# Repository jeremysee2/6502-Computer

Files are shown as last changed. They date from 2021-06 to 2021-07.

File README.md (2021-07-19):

# 6502 Computer based on Ben Eater

While following along Ben Eater's 6502 video series, I attempted to follow along with a breadboard version. However, I found that connecting wires across the breadboard was often confusing and I had to debug a mis-connection more than once. To make things easier on myself, I set out to design my own PCB, following the schematics he had posted on his [website](https://eater.net/6502).

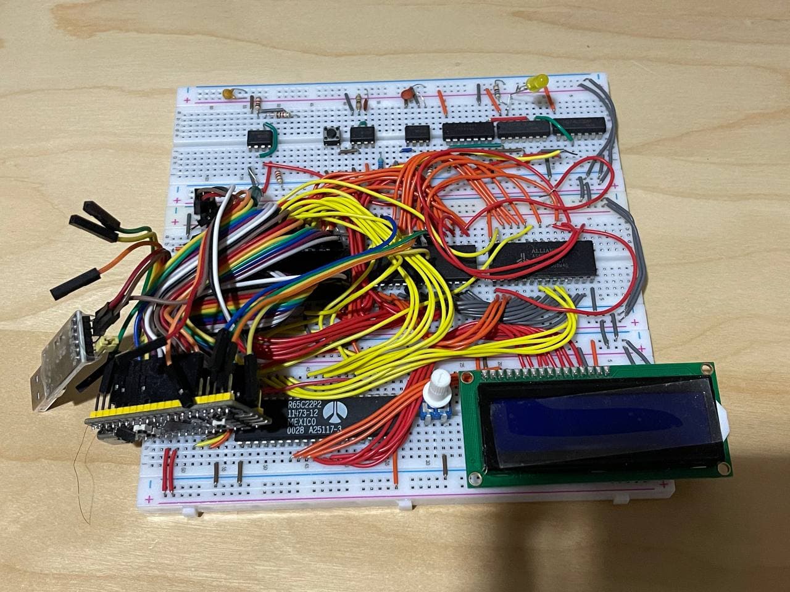
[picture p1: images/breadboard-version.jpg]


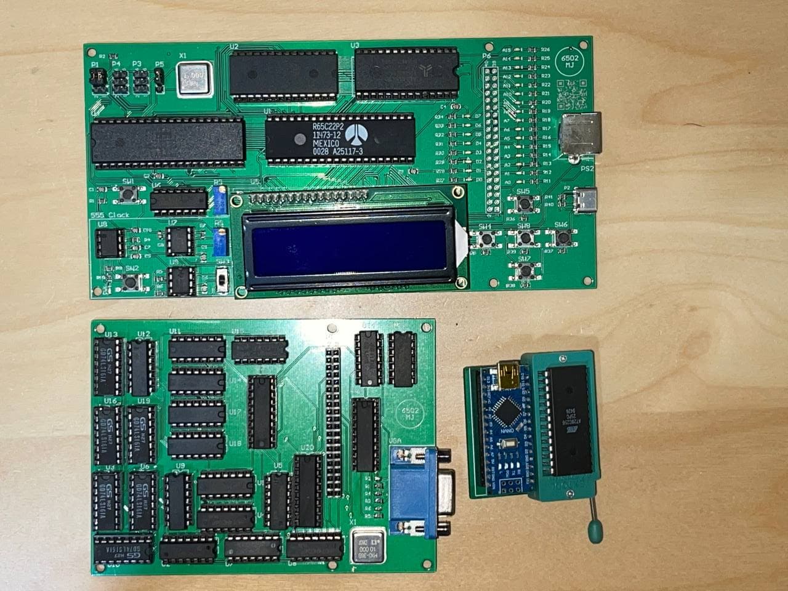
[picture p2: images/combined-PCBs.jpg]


Note that there are two revisions of these boards, as I found some mistakes when fabricating Revision A. In Revision B, I fixed the crystal oscillator footprints (accidentally mirrored them) and 

## 6502 Main PCB

The main PCB follows Ben Eater's 6502 series, comprising the 6502 processor, 62256 SRAM, 28C256 EEPROM, and 65C22 Interface Adapter. Additionally, I incorporated his 555 based clock generator, and PS2 interface. The schematic for this PCB is available [here](PCBs/Rev-B/6502/6502.pdf).

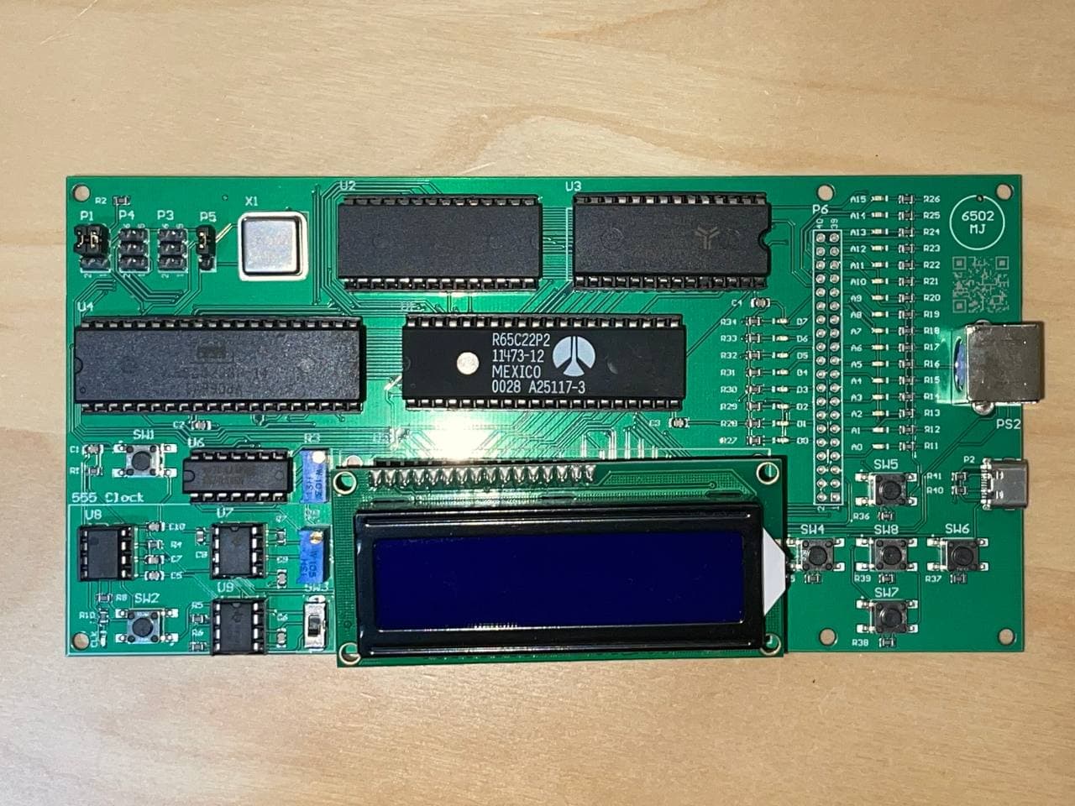
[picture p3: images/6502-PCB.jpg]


## VGA PCB

This follows Ben Eater's [World's Worst Video Card](https://eater.net/vga) series. This comprises a bunch of 74-series logic gates to count VGA clock pulses, which is used to generate appropriate `HSYNC` and `VSYNC` signals for a screen resolution of 200x150 at 10MHz. The schematic for this PCB is available [here](PCBs/Rev-B/6502_VGA/6502_VGA.pdf).

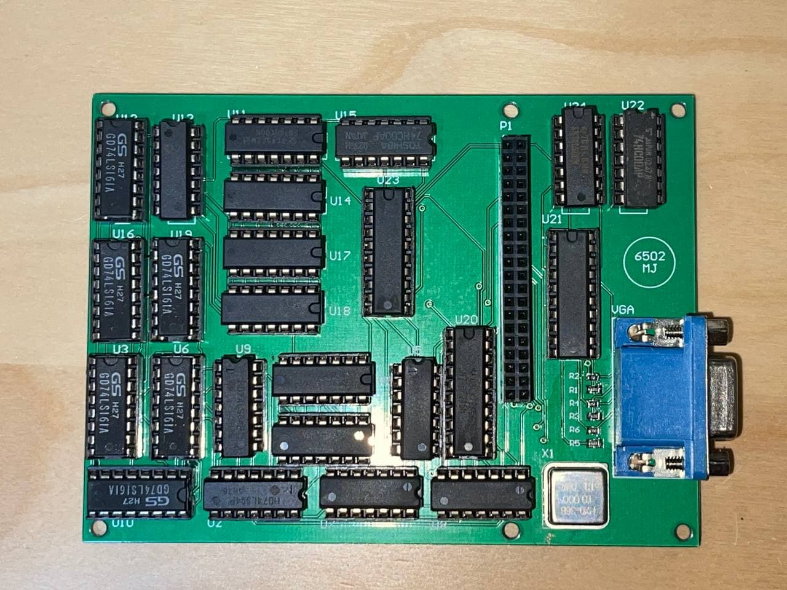
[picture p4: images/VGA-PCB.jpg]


## EEPROM Programmer

This is simply a PCB version of the [EEPROM Programmer](https://github.com/beneater/eeprom-programmer). The schematic for this PCB is available [here](PCBs/Rev-B/EEPROM_Programmer/EEPROM_Programmer.pdf).

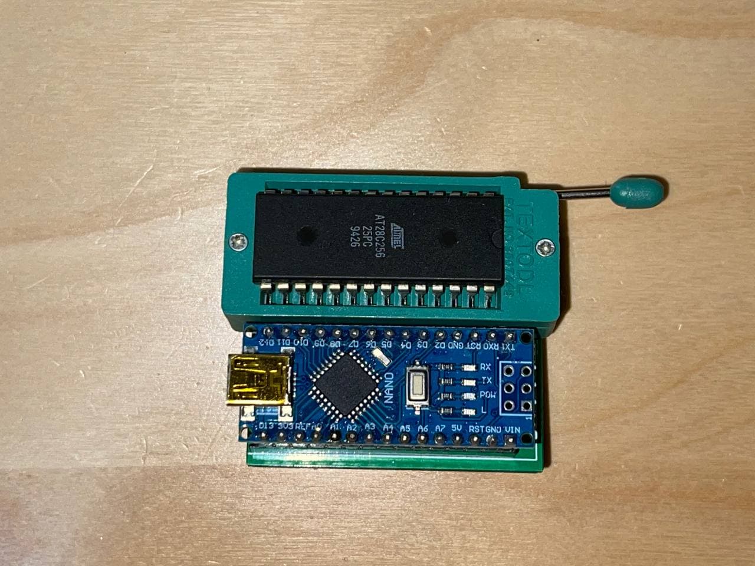
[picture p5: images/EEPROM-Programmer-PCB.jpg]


## Ordering the PCBs

Zip the contents of the "fabrication" folders, that will be the Gerber files you send to your PCB manufacturer. I recommend getting the SMT components (passives, LEDs, USB-C connectors) assembled for you as it can be a pain to solder them without a hot air gun. Get the files for the [6502 Carrier Board](PCBs/Rev-B/6502/fabrication), [VGA Board](vga/../PCBs/Rev-B/6502/fabrication) and [EEPROM Programmer Board](eeprom_programmer/../PCBs/Rev-B/EEPROM_Programmer/fabrication).

For the components, I recommend you buy them from Ben Eater's store for the [6502](https://eater.net/6502), [Clock module](https://eater.net/shop), the [VGA Board](https://eater.net/vga), [EEPROM Programmer (TL866)](https://eater.net/shop). The components for the PS2 circuit are not yet available from his store; you'll need to buy the 74-series logic chips yourself. If you want to buy the components yourself, I still recommend at least getting the 6502 kit and the EEPROM programmer from his store, as I've found that it can be hard to buy genuine "W65C02" chips.

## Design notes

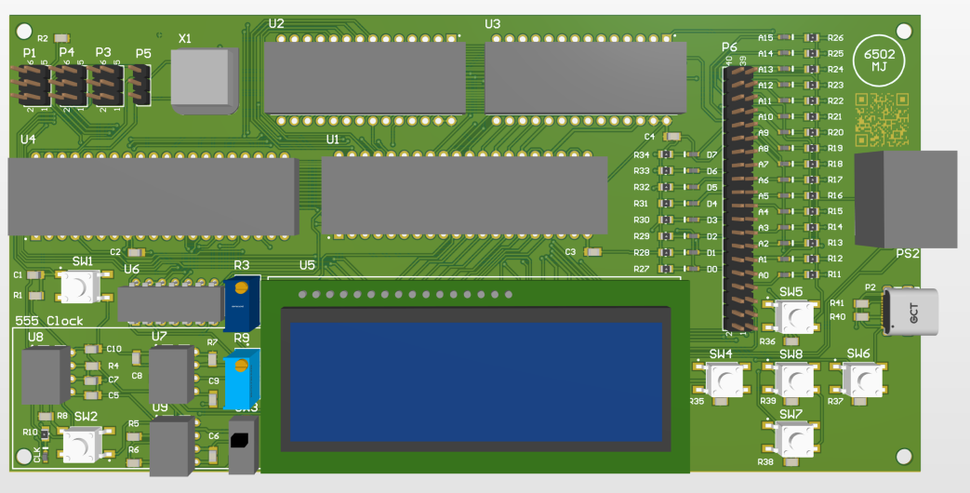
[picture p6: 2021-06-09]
PCBs/Rev-B/6502/3dModel_6502.PNG

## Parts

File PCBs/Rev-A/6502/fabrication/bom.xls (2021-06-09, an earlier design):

Comment | Designator | Package | LCSC Part
19-217/GHC-YR1S2/3T | D0,D1,D2,D3,D4,D5,D6,D7 | EVRL-0603-2_V | C72043
GRM21BR71H104KA01L | C1,C2,C3,C4,C7,C10,C11,C12 | CAPC2013X135X45ML10T25 | C49678
GRM216R61E105KA12D | C8 | CAPC2013X70X45NL10T25 | C28323
19-217/BHC-ZL1M2RY/3T | A0,A1,A2,A3,A4,A5,A6,A7,A8,A9,A10,A11,A12,A13,A14,A15,CLK | EVRL-0603-2_V | C72041
0805W8F5101T5E | R40,R41 | RESC2013X50X30NL20T20 | C27834
CRCW0805220RFKEA | R10,R11,R12,R13,R14,R15,R16,R17,R18,R19,R20,R21,R22,R23,R24,R25,R26,R27,R28,R29,R30,R31,R32,R33,R34 | FP-CRCW0805-E3-MFG | C17557
Diode, General Purpose | D8 | DO-214AC/SMA | C412437
CRCW08051M00JNEA | R4 | RESC2013X50X30NL20T20 | C17514
GRM216R71H103KA01D | C5,C6,C9 | CAPC2013X70X45ML10T25 | C1710
K2-1102SP-C4SC-04 | SW1,SW2,SW4,SW5,SW6,SW7,SW8 | TECO-FSM4JSMA_V | C127509
CRCW08051K00FKEA | R1,R2,R5,R6,R7,R8,R35,R36,R37,R38,R39 | RESC2013X50X30NL20T20 | C17513
0805W8F3302T5E | R42 | RESC2013X50X30NL20T20 | C17633

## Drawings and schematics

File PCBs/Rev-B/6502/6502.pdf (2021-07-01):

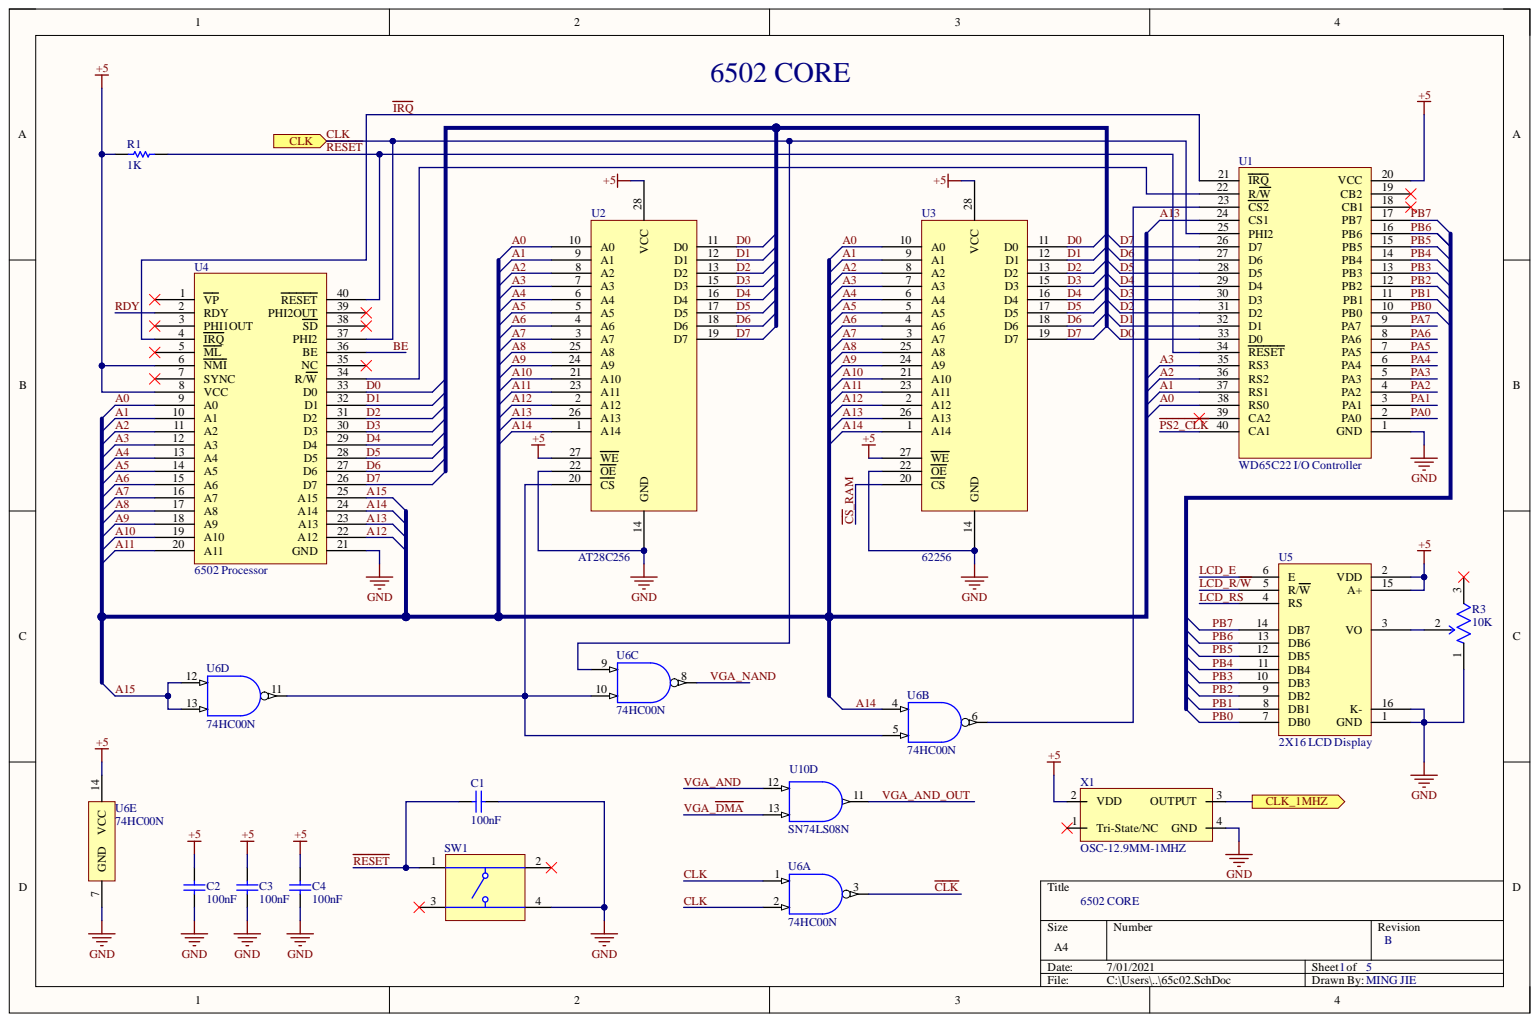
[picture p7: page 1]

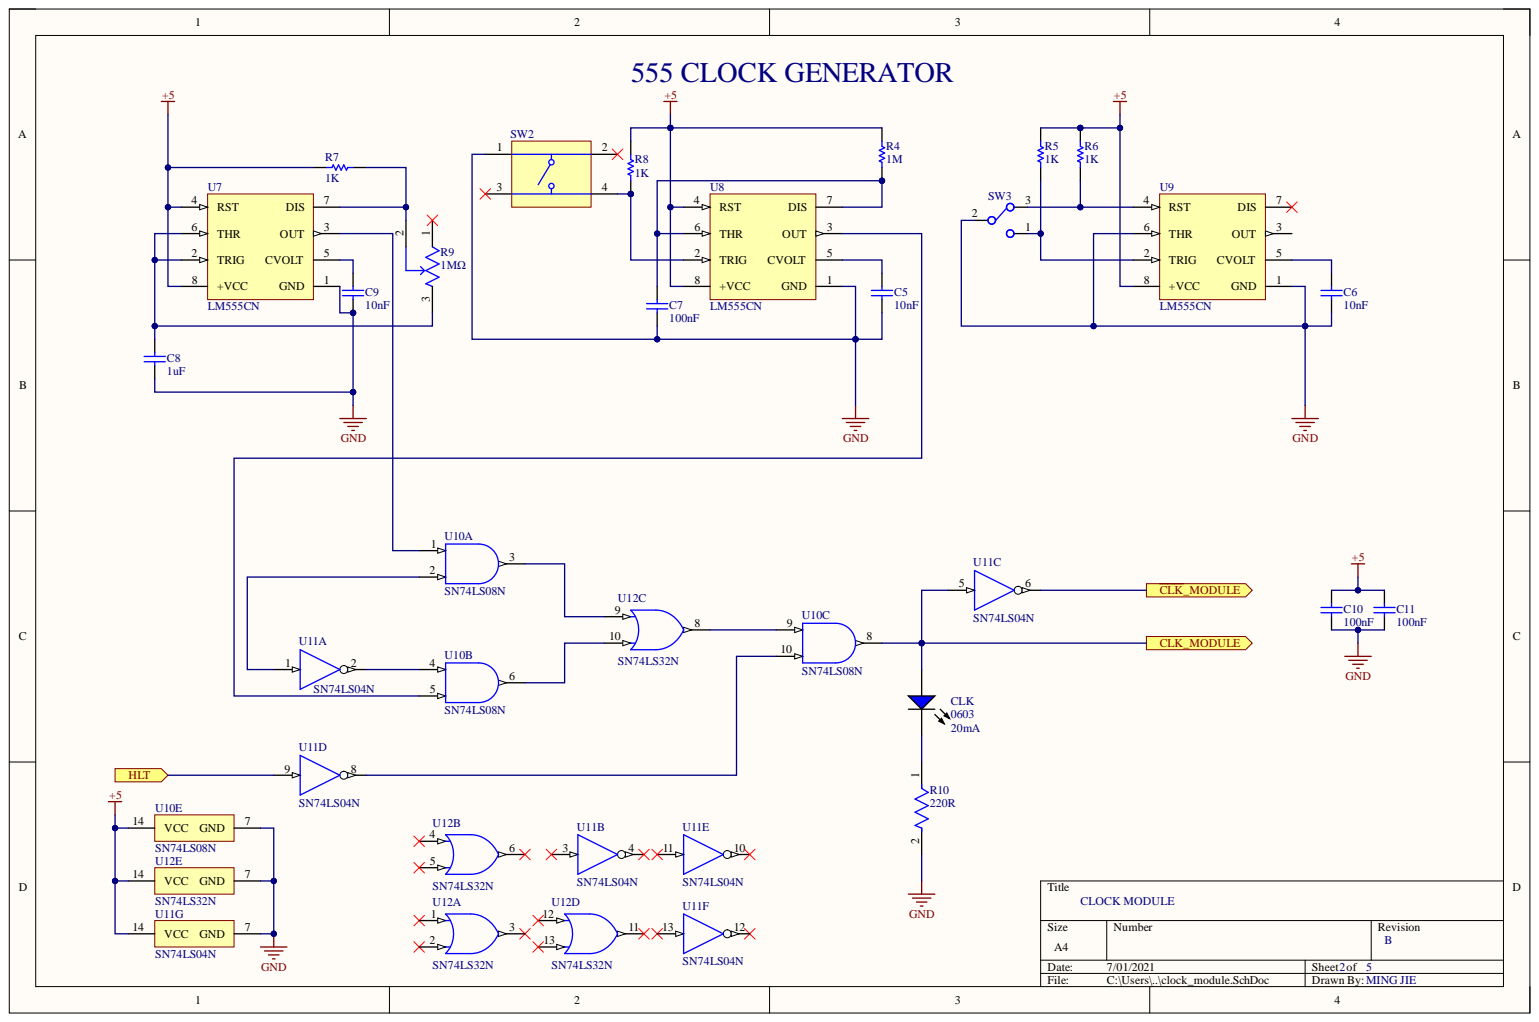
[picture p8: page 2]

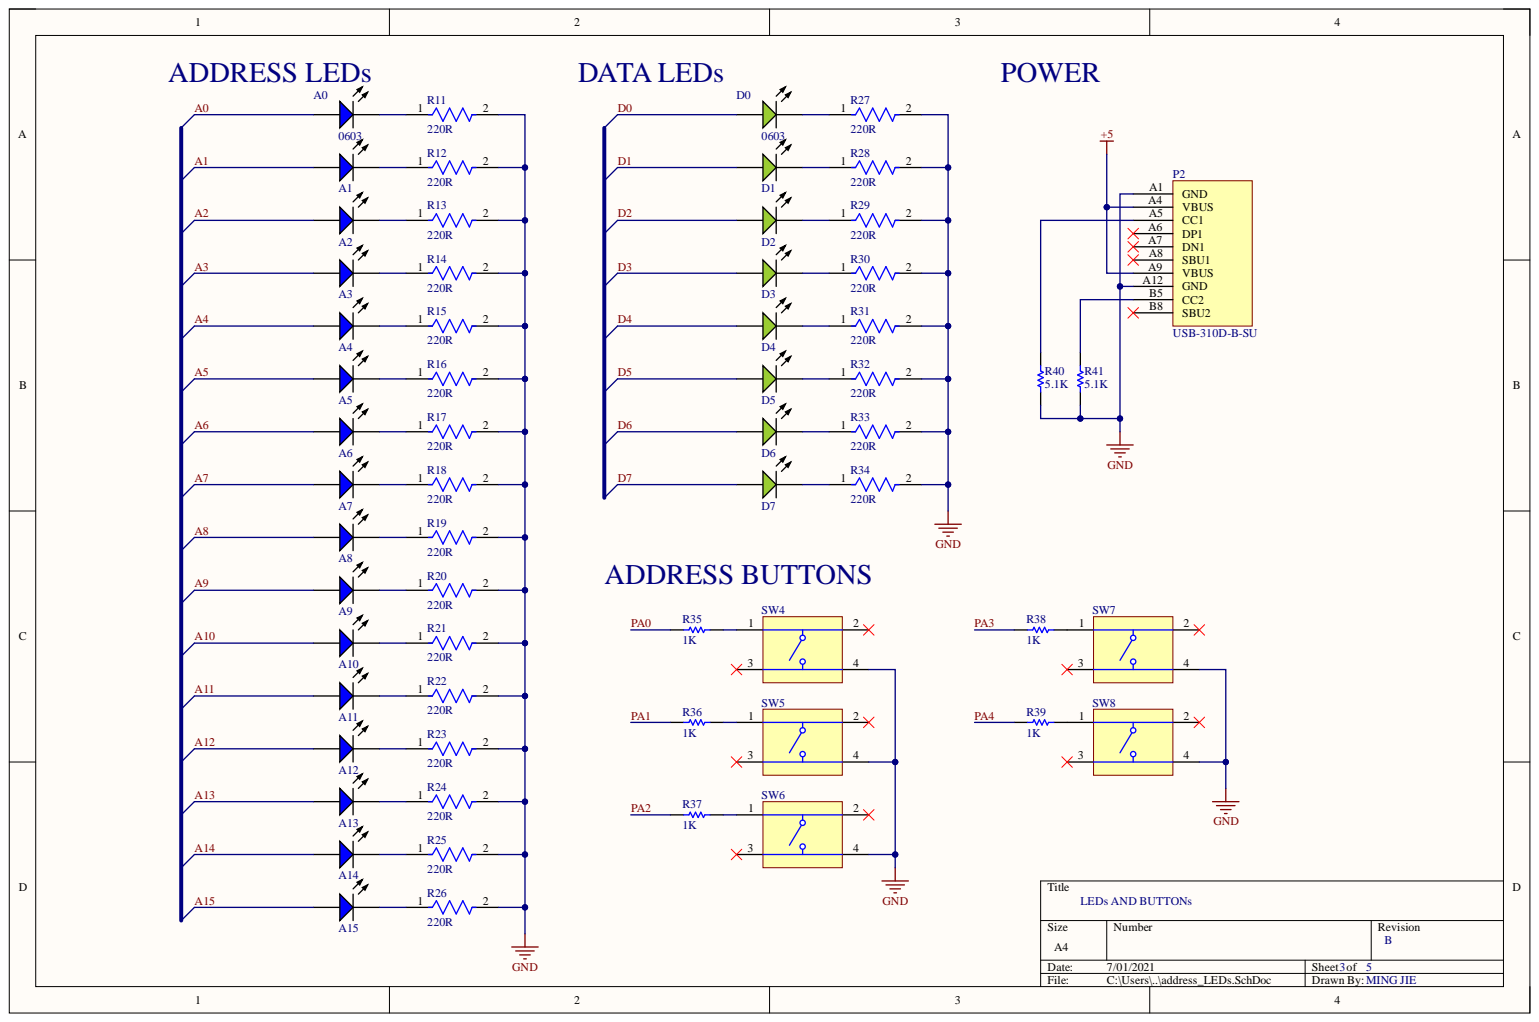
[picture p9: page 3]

A 4
A 5
A 6

A 1 2
CC2 B5

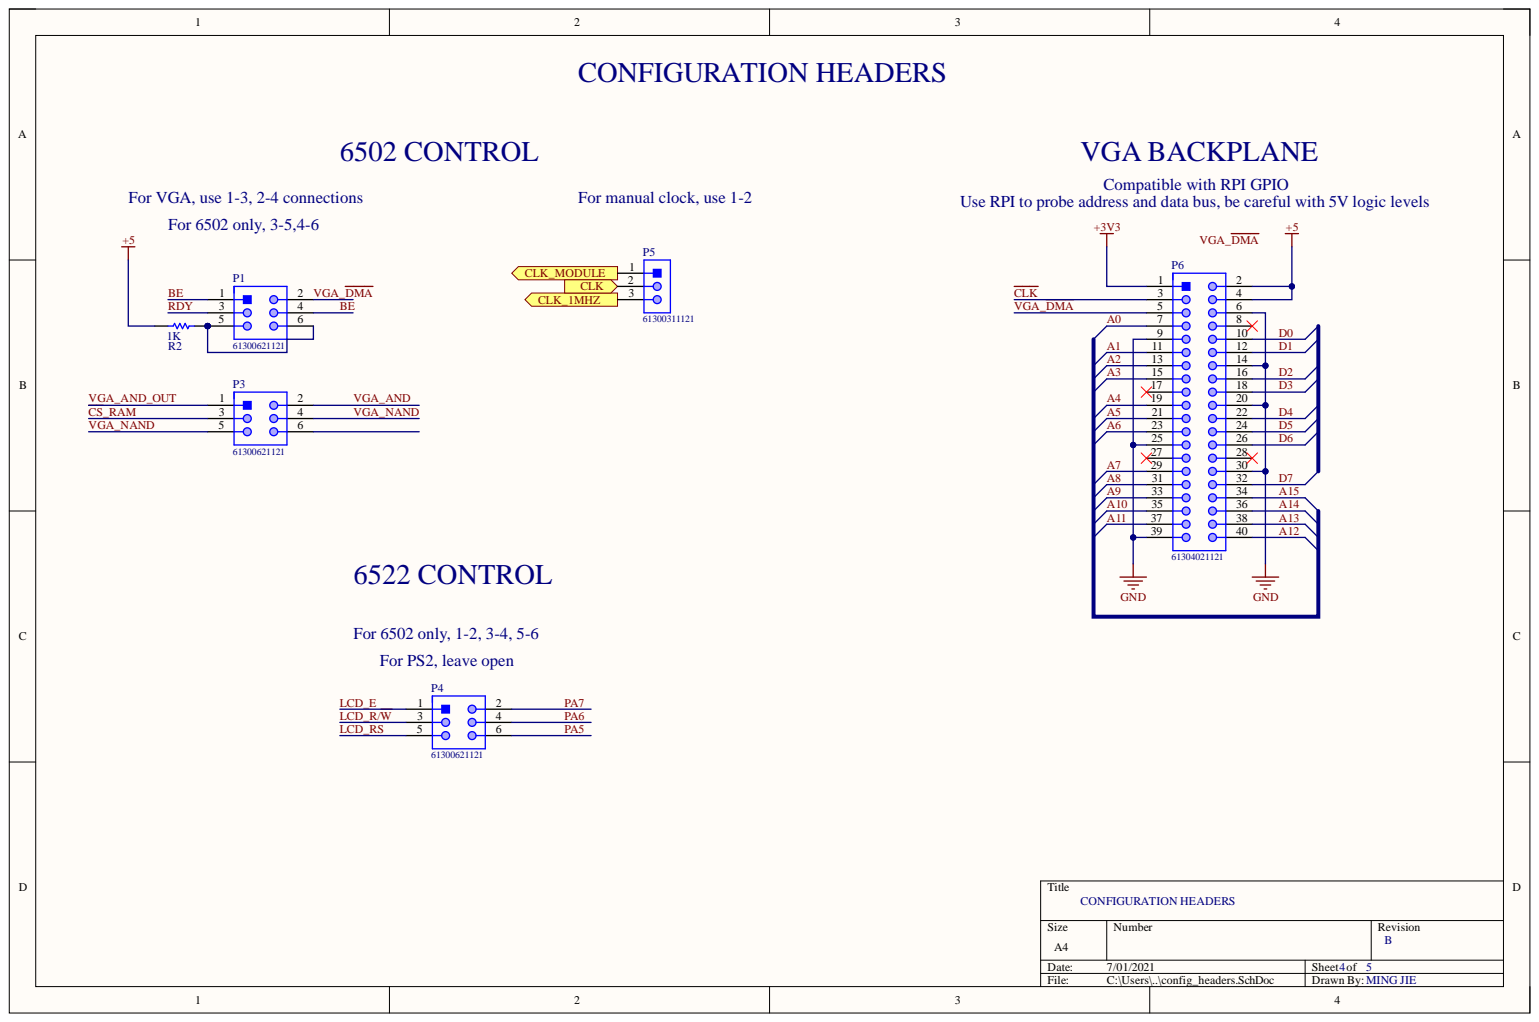
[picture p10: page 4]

to probe address and data bus, be careful

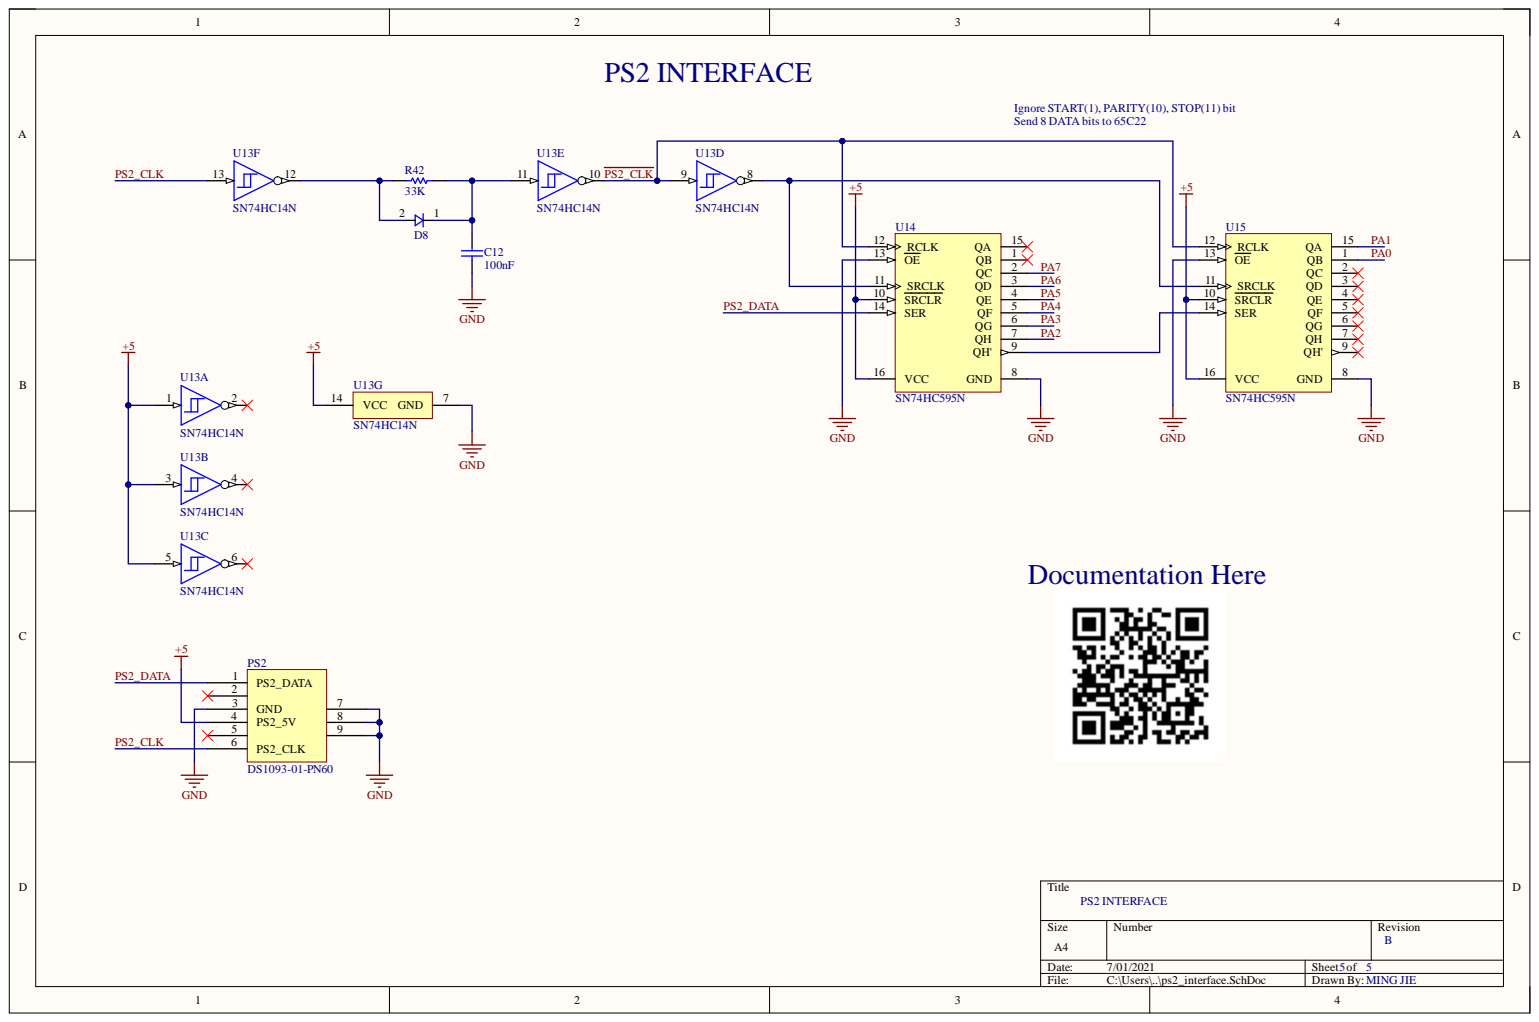
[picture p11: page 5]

Ignore START(1), PARITY(10), STOP(11) bit
Send 8 DATA bits to 65C22

PS2_5V 4 | 8

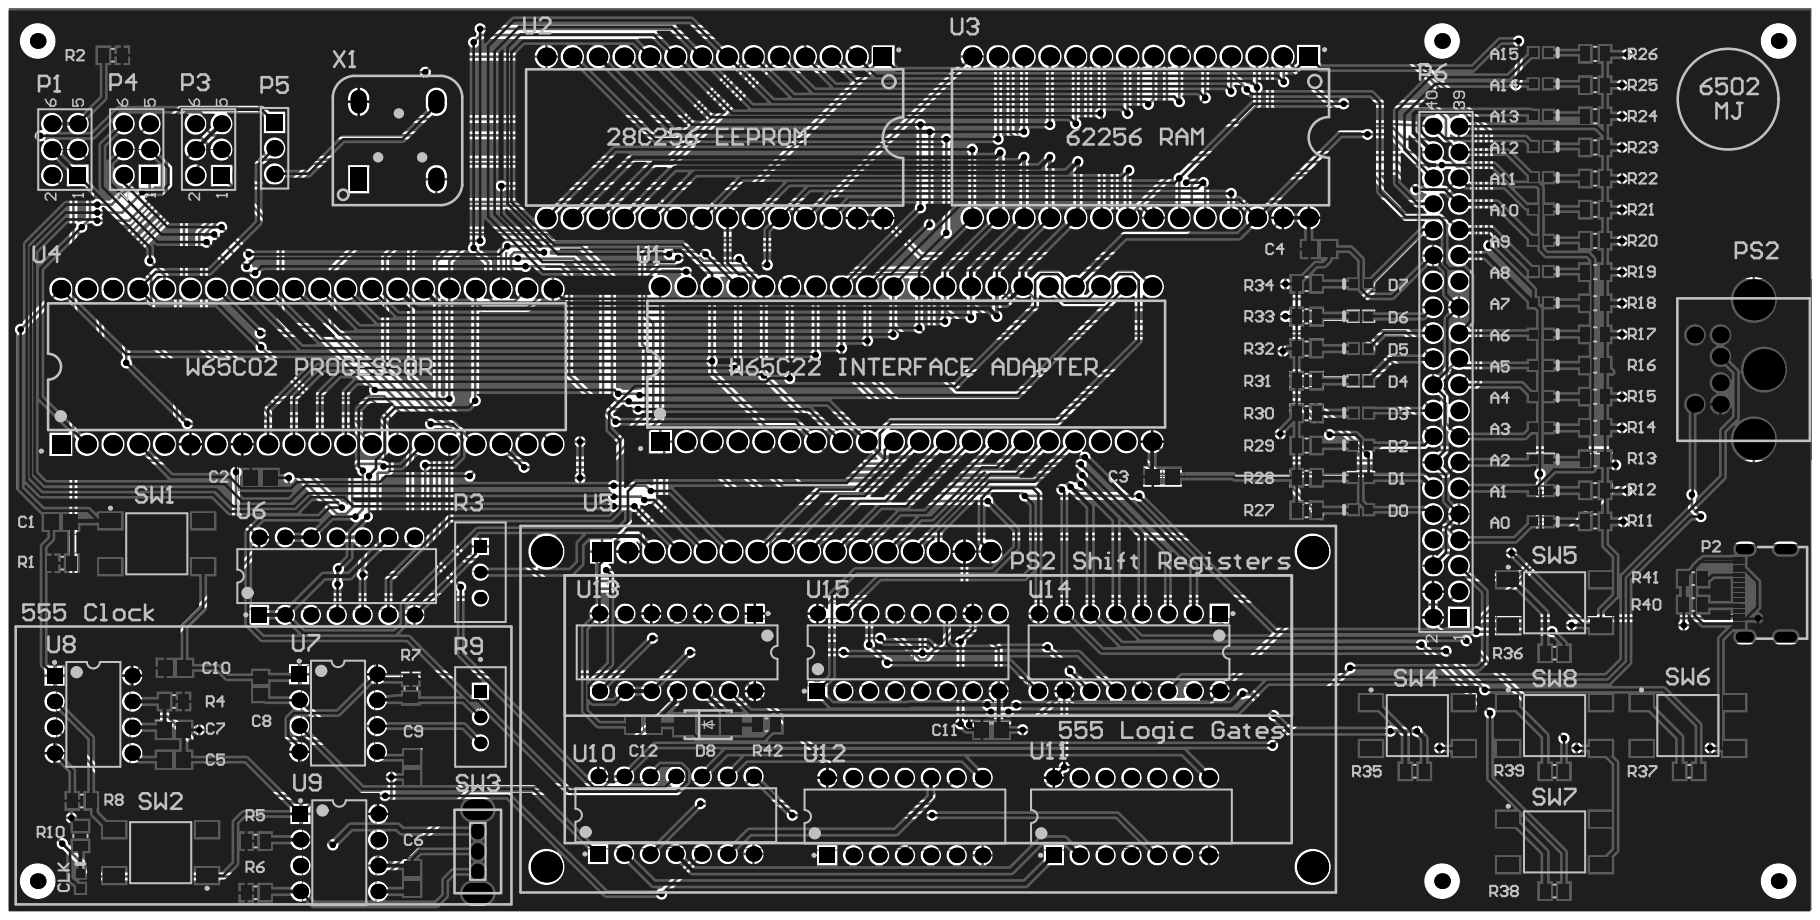
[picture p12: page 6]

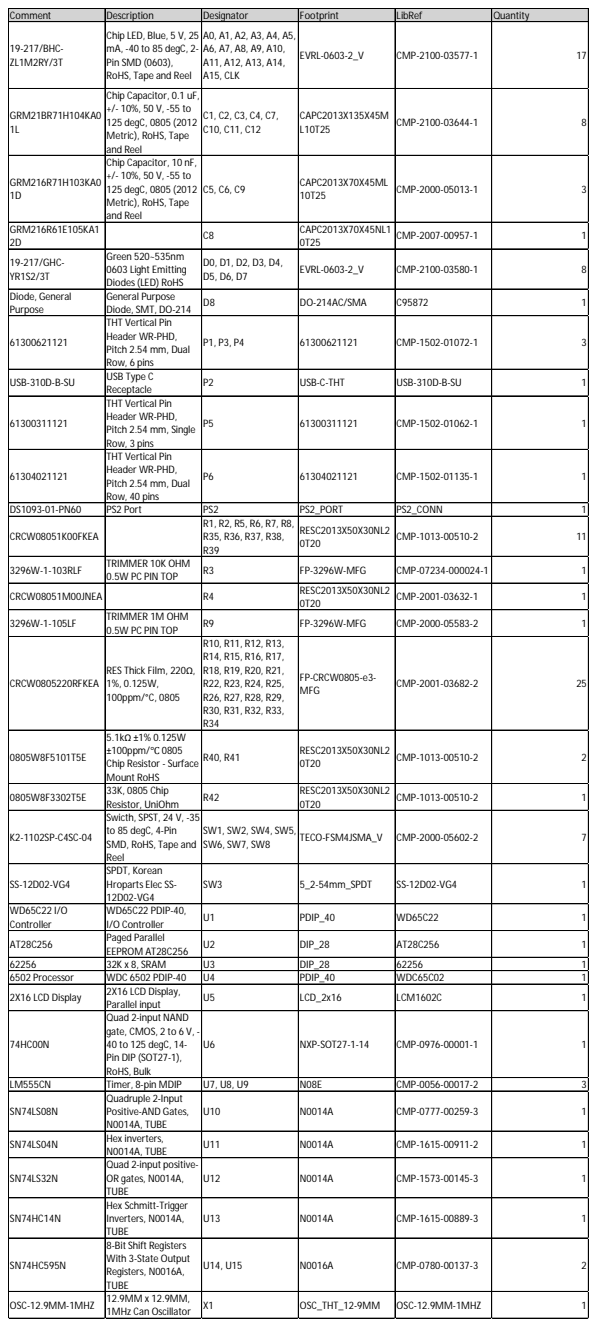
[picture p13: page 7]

Comment | Description | Designator | Footprint | LibRef | Quantity
19-217/BHC-ZL1M2RY/3T | Chip LED, Blue, 5 V, 25 mA, -40 to 85 degC, 2-Pin SMD (0603), RoHS, Tape and Reel | A0, A1, A2, A3, A4, A5, A6, A7, A8, A9, A10, A11, A12, A13, A14, A15, CLK | EVRL-0603-2_V | CMP-2100-03577-1 | 17

GRM21BR71H104KA0 1L | Chip Capacitor, 0.1 uF, +/- 10%, 50 V, -55 to 125 degC, 0805 (2012 Metric), RoHS, Tape and Reel | C1, C2, C3, C4, C7, C10, C11, C12 | CAPC2013X135X45M L10T25 | CMP-2100-03644-1 | 8

GRM216R71H103KA0 1D | Chip Capacitor, 10 nF, +/- 10%, 50 V, -55 to 125 degC, 0805 (2012 Metric), RoHS, Tape and Reel | C5, C6, C9 | CAPC2013X70X45ML 10T25 | CMP-2000-05013-1 | 3

GRM216R61E105KA1 2D | | C8 | CAPC2013X70X45NL1 0T25 | CMP-2007-00957-1 | 1

19-217/GHC-YR1S2/3T | Green 520~535nm 0603 Light Emitting Diodes (LED) RoHS | D0, D1, D2, D3, D4, D5, D6, D7 | EVRL-0603-2_V | CMP-2100-03580-1 | 8

Diode, General Purpose | General Purpose Diode, SMT, DO-214 | D8 | DO-214AC/SMA | C95872 | 1

61300621121 | THT Vertical Pin Header WR-PHD, Pitch 2.54 mm, Dual Row, 6 pins | P1, P3, P4 | 61300621121 | CMP-1502-01072-1 | 3

USB-310D-B-SU | USB Type C Receptacle | P2 | USB-C-THT | USB-310D-B-SU | 1

61300311121 | THT Vertical Pin Header WR-PHD, Pitch 2.54 mm, Single Row, 3 pins | P5 | 61300311121 | CMP-1502-01062-1 | 1

61304021121 | THT Vertical Pin Header WR-PHD, Pitch 2.54 mm, Dual Row, 40 pins | P6 | 61304021121 | CMP-1502-01135-1 | 1

DS1093-01-PN60 | PS2 Port | PS2 | PS2_PORT | PS2_CONN | 1
CRCW08051K00FKEA | | R1, R2, R5, R6, R7, R8, R35, R36, R37, R38, R39 | RESC2013X50X30NL2 0T20 | CMP-1013-00510-2 | 11

3296W-1-103RLF | TRIMMER 10K OHM 0.5W PC PIN TOP | R3 | FP-3296W-MFG | CMP-07234-000024-1 | 1

CRCW08051M00JNEA | | R4 | RESC2013X50X30NL2 0T20 | CMP-2001-03632-1 | 1

3296W-1-105LF | TRIMMER 1M OHM 0.5W PC PIN TOP | R9 | FP-3296W-MFG | CMP-2000-05583-2 | 1

CRCW0805220RFKEA | RES Thick Film, 220Ω, 1%, 0.125W, 100ppm/°C, 0805 | R10, R11, R12, R13, R14, R15, R16, R17, R18, R19, R20, R21, R22, R23, R24, R25, R26, R27, R28, R29, R30, R31, R32, R33, R34 | FP-CRCW0805-e3-MFG | CMP-2001-03682-2 | 25

0805W8F5101T5E | 5.1kΩ ±1% 0.125W ±100ppm/℃ 0805 Chip Resistor - Surface Mount RoHS | R40, R41 | RESC2013X50X30NL2 0T20 | CMP-1013-00510-2 | 2

0805W8F3302T5E | 33K, 0805 Chip Resistor, UniOhm | R42 | RESC2013X50X30NL2 0T20 | CMP-1013-00510-2 | 1

K2-1102SP-C4SC-04 | Swicth, SPST, 24 V, -35 to 85 degC, 4-Pin SMD, RoHS, Tape and Reel | SW1, SW2, SW4, SW5, SW6, SW7, SW8 | TECO-FSM4JSMA_V | CMP-2000-05602-2 | 7

SS-12D02-VG4 | SPDT, Korean Hroparts Elec SS-12D02-VG4 | SW3 | 5_2-54mm_SPDT | SS-12D02-VG4 | 1

WD65C22 I/O Controller | WD65C22 PDIP-40, I/O Controller | U1 | PDIP_40 | WD65C22 | 1

AT28C256 | Paged Parallel EEPROM AT28C256 | U2 | DIP_28 | AT28C256 | 1

62256 | 32K x 8, SRAM | U3 | DIP_28 | 62256 | 1
6502 Processor | WDC 6502 PDIP-40 | U4 | PDIP_40 | WDC65C02 | 1
2X16 LCD Display | 2X16 LCD Display, Parallel input | U5 | LCD_2x16 | LCM1602C | 1

74HC00N | Quad 2-input NAND gate, CMOS, 2 to 6 V, -40 to 125 degC, 14-Pin DIP (SOT27-1), RoHS, Bulk | U6 | NXP-SOT27-1-14 | CMP-0976-00001-1 | 1

LM555CN | Timer, 8-pin MDIP | U7, U8, U9 | N08E | CMP-0056-00017-2 | 3
SN74LS08N | Quadruple 2-Input Positive-AND Gates, N0014A, TUBE | U10 | N0014A | CMP-0777-00259-3 | 1

SN74LS04N | Hex inverters, N0014A, TUBE | U11 | N0014A | CMP-1615-00911-2 | 1

SN74LS32N | Quad 2-input positive-OR gates, N0014A, TUBE | U12 | N0014A | CMP-1573-00145-3 | 1

SN74HC14N | Hex Schmitt-Trigger Inverters, N0014A, TUBE | U13 | N0014A | CMP-1615-00889-3 | 1

SN74HC595N | 8-Bit Shift Registers With 3-State Output Registers, N0016A, TUBE | U14, U15 | N0016A | CMP-0780-00137-3 | 2

OSC-12.9MM-1MHZ | 12.9MM x 12.9MM, 1MHz Can Oscillator | X1 | OSC_THT_12-9MM | OSC-12.9MM-1MHZ | 1

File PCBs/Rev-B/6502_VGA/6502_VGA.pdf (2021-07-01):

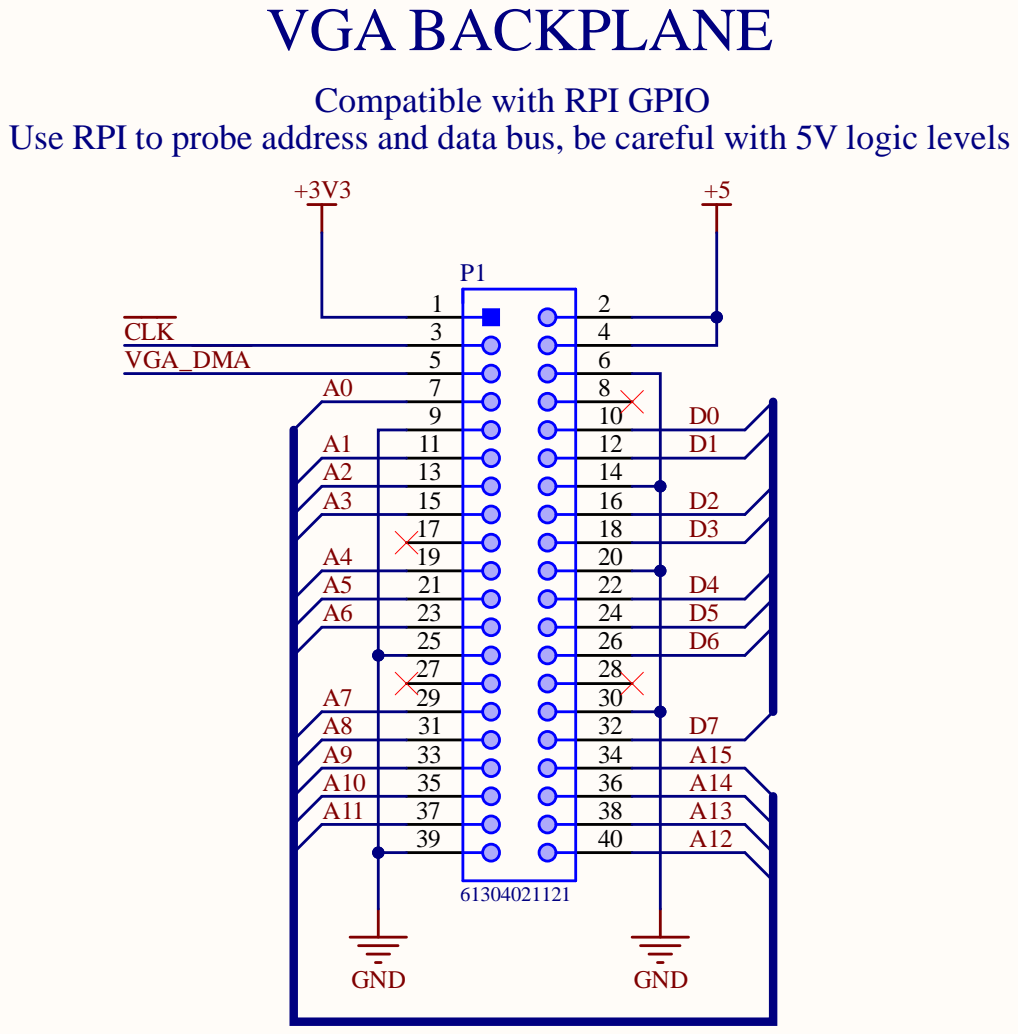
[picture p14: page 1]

to probe address and data bus, be careful

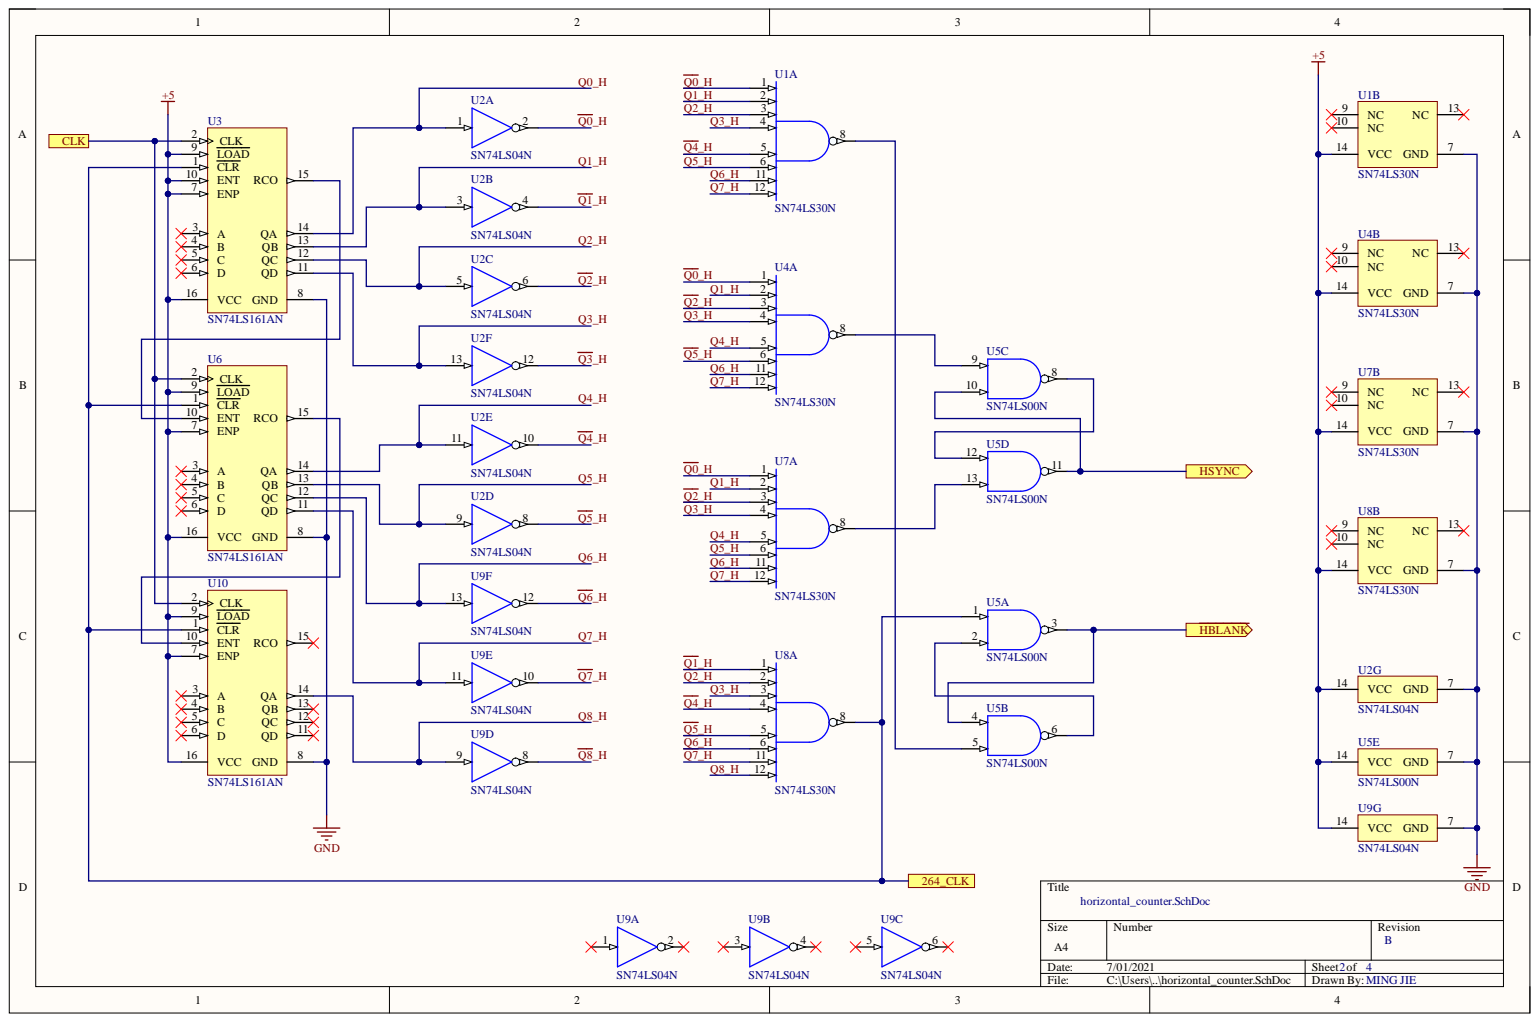
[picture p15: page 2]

4 | | 1 3
5 | | 1 2 | | 2
6 | | 1 1

4 | 1 3
5 | 1 2 | U 2 D | 5
6 | 1 1

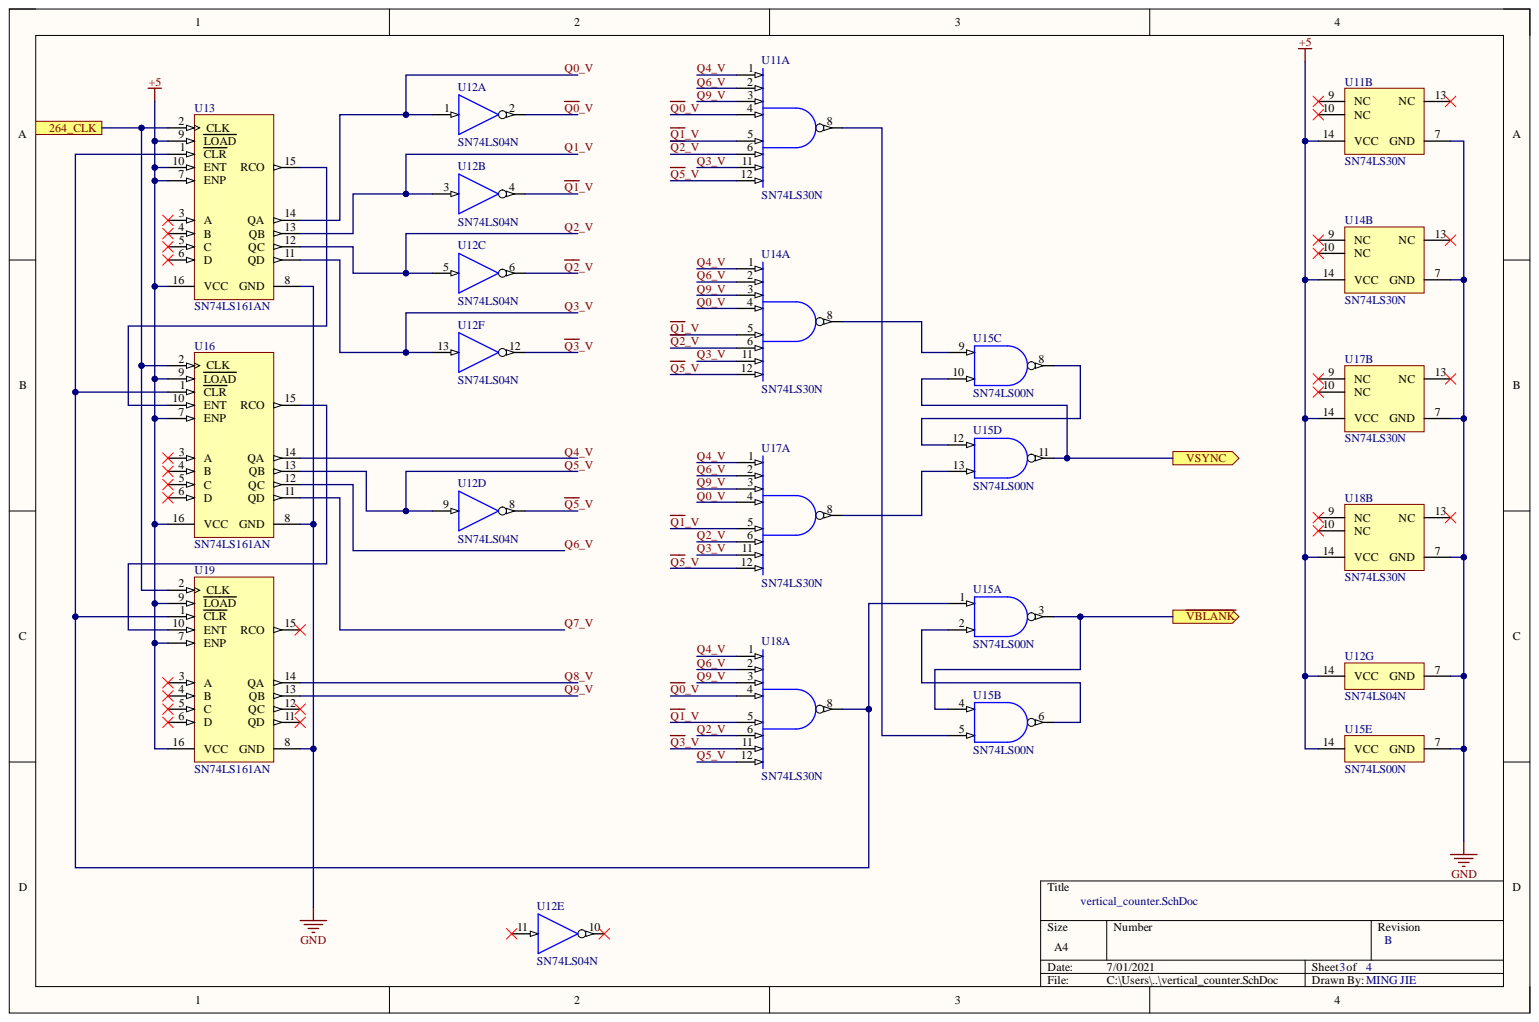
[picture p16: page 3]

4 | 1 3
5 | 1 2
6 | 1 1

1 0
7 | 1 4

4 | 1 3 | Q 5
1 6 | 8 | | 9 | 8 | Q

1 0 | E N T RCO E N P A Q A B Q B C Q C D Q D VCC G N D | 1 5 | SN 7 4 LS3 0 N
7 | | 1 4

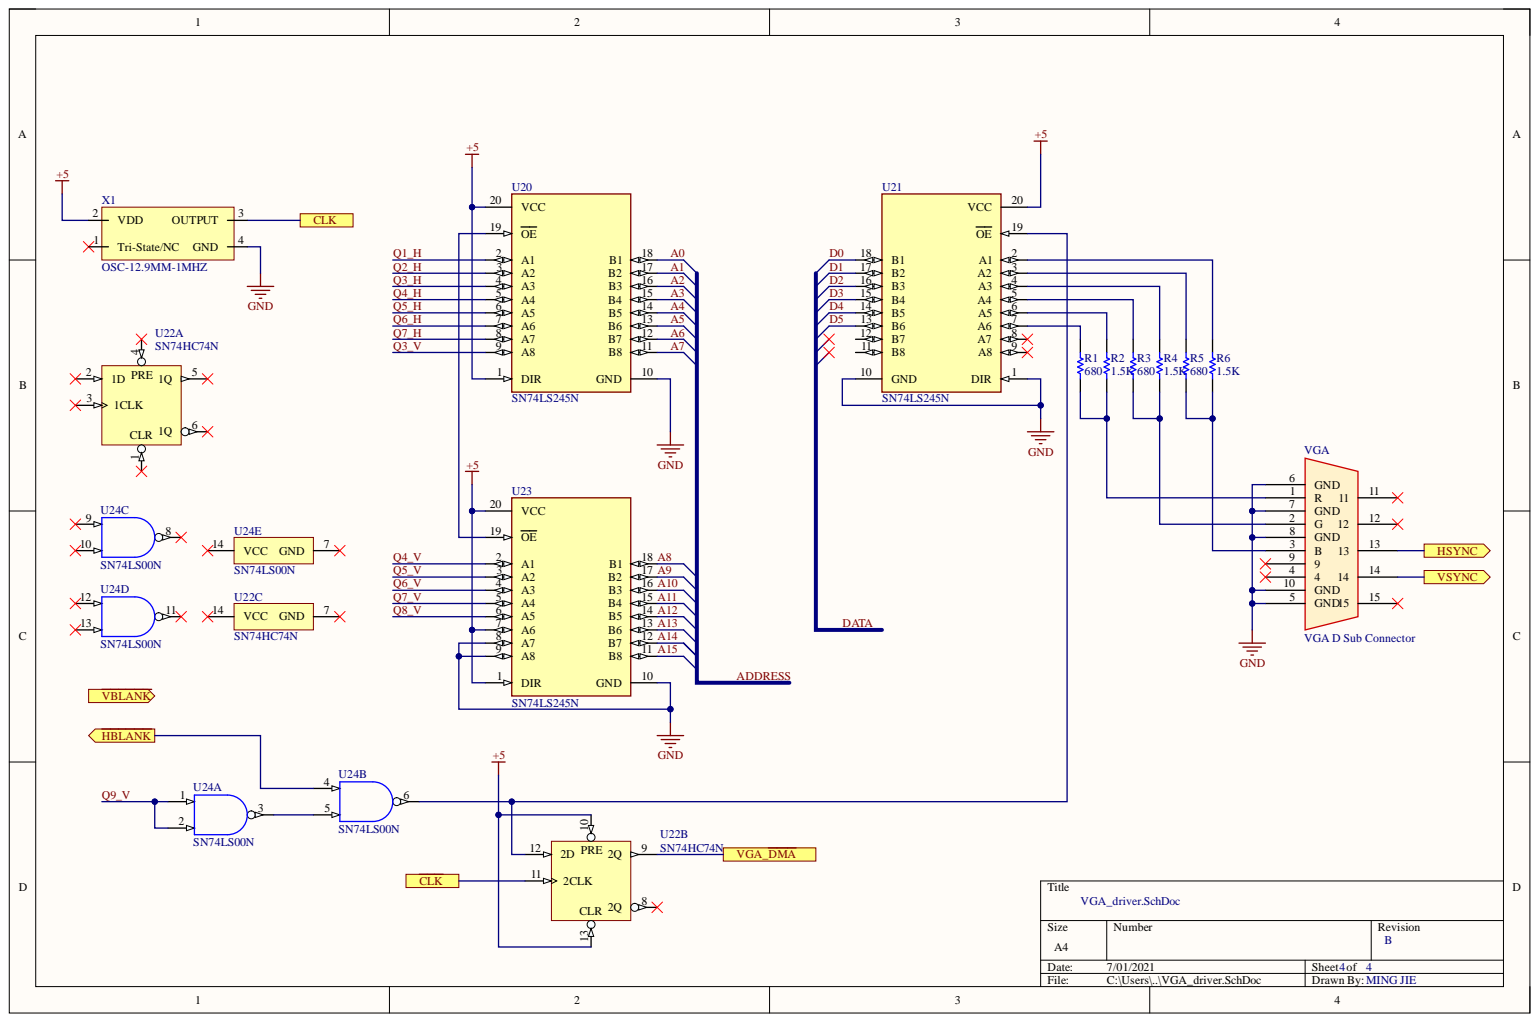
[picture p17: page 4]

A1 2
A2 3
A3 4
A4 5

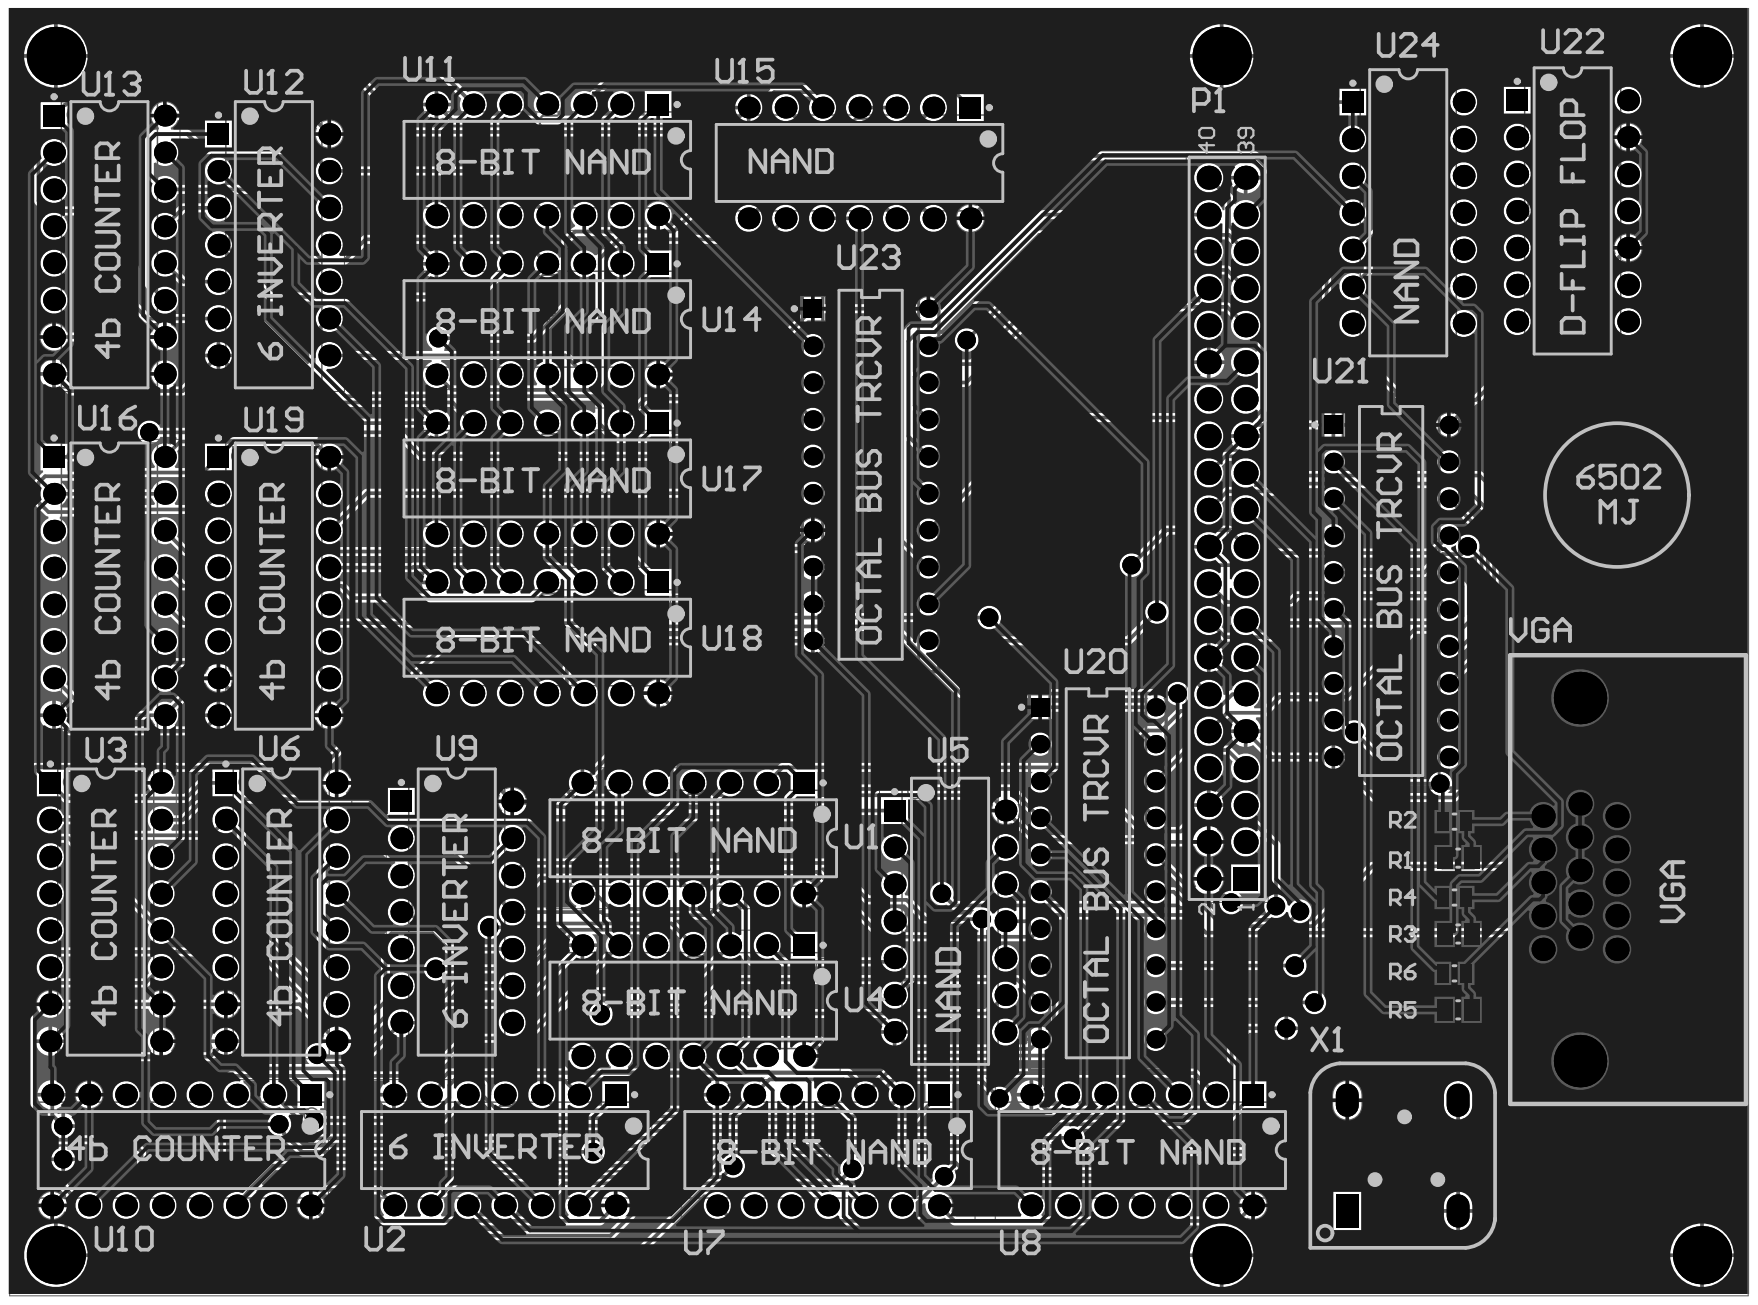
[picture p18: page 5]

Comment | Description | Designator | Footprint | LibRef | Quantity
61304021121 | THT Vertical Pin Header WR-PHD, Pitch 2.54 mm, Dual Row, 40 pins | P1 | 61304021121 | CMP-1502-01135-1 | 1
CRCW0805680RFKEA | | R1, R3, R5 | RESC2013X50X30NL2 0T20 | CMP-2001-04066-1 | 3
RC0805FR-071K5L | RES 1.50K OHM 1/8W 1% 0805 SMD | R2, R4, R6 | RESC2013X60X35LL10 T20 | CMP-1659-00010-2 | 3
SN74LS30N | 8-input positive-NAND gates, N0014A, TUBE | U1, U4, U7, U8, U11, U14, U17, U18 | N0014A | CMP-1627-00459-2 | 8
SN74LS04N | Hex inverters, N0014A, TUBE | U2, U9, U12 | N0014A | CMP-1615-00911-2 | 3
SN74LS161AN | Synchronous 4-Bit Binary Counters, N0016A, TUBE | U3, U6, U10, U13, U16, U19 | N0016A | CMP-1623-00512-2 | 6
SN74LS00N | Quad 2-input positive-NAND gates, N0014A, TUBE | U5, U15, U24 | N0014A | CMP-1627-00476-2 | 3
SN74LS245N | IC TXRX NON-INVERT 5.25V 20DIP | U20, U21, U23 | FP-N0020A-MFG | CMP-1620-00419-3 | 3
SN74HC74N | Dual D-Type Positive-Edge-Triggered Flip-Flops With Clear and Preset, N0014A, TUBE | U22 | N0014A | CMP-1616-00096-3 | 1
VGA D Sub Connector | VGA D Sub Connector | VGA | VGA | VGA-002 | 1
OSC-12.9MM-1MHZ | 12.9MM x 12.9MM, 1MHz Can Oscillator | X1 | OSC_THT_12-9MM | OSC-12.9MM-1MHZ | 1

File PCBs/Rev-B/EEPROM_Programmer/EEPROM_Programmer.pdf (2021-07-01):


ARDUINO NANO EEPROM PROGRAMMER

2 3

1 4 | | 5
1 6 | | 6



Comment | Description | Designator | Footprint | LibRef | Quantity
Arduino Nano | Arduino Nano board | MD1 | ARDUINO_NANO | Arduino_Nano | 1
AT28C256 | Paged Parallel EEPROM AT28C256 | U1 | DIP_28 | AT28C256 | 1

SN74HC595N | 8-Bit Shift Registers With 3-State Output Registers, N0016A, TUBE | U2, U3 | N0016A | CMP-0780-00137-3 | 2

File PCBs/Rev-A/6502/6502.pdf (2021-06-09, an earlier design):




A 4
A 5
A 6

A 1 2
CC2 B5


to probe address and data bus, be careful


Ignore START(1), PARITY(10), STOP(11) bit
Send 8 DATA bits to 65C22

PS2_5V 4 | 8



Comment | Description | Designator | Footprint | LibRef | Quantity
19-217/BHC-ZL1M2RY/3T | Chip LED, Blue, 5 V, 25 mA, -40 to 85 degC, 2-Pin SMD (0603), RoHS, Tape and Reel | A0, A1, A2, A3, A4, A5, A6, A7, A8, A9, A10, A11, A12, A13, A14, A15, CLK | EVRL-0603-2_V | CMP-2100-03577-1 | 17

GRM21BR71H104KA0 1L | Chip Capacitor, 0.1 uF, +/- 10%, 50 V, -55 to 125 degC, 0805 (2012 Metric), RoHS, Tape and Reel | C1, C2, C3, C4, C7, C10, C11, C12 | CAPC2013X135X45M L10T25 | CMP-2100-03644-1 | 8

GRM216R71H103KA0 1D | Chip Capacitor, 10 nF, +/- 10%, 50 V, -55 to 125 degC, 0805 (2012 Metric), RoHS, Tape and Reel | C5, C6, C9 | CAPC2013X70X45ML 10T25 | CMP-2000-05013-1 | 3

GRM216R61E105KA1 2D | | C8 | CAPC2013X70X45NL1 0T25 | CMP-2007-00957-1 | 1

19-217/GHC-YR1S2/3T | Green 520~535nm 0603 Light Emitting Diodes (LED) RoHS | D0, D1, D2, D3, D4, D5, D6, D7 | EVRL-0603-2_V | CMP-2100-03580-1 | 8

Diode, General Purpose | General Purpose Diode, SMT, DO-214 | D8 | DO-214AC/SMA | C95872 | 1

61300621121 | THT Vertical Pin Header WR-PHD, Pitch 2.54 mm, Dual Row, 6 pins | P1, P3, P4 | 61300621121 | CMP-1502-01072-1 | 3

USB-310D-B-SU | USB Type C Receptacle | P2 | USB-C-THT | USB-310D-B-SU | 1

61300311121 | THT Vertical Pin Header WR-PHD, Pitch 2.54 mm, Single Row, 3 pins | P5 | 61300311121 | CMP-1502-01062-1 | 1

61304021121 | THT Vertical Pin Header WR-PHD, Pitch 2.54 mm, Dual Row, 40 pins | P6 | 61304021121 | CMP-1502-01135-1 | 1

DS1093-01-PN60 | PS2 Port | PS2 | PS2_PORT | PS2_CONN | 1
CRCW08051K00FKEA | | R1, R2, R5, R6, R7, R8, R35, R36, R37, R38, R39 | RESC2013X50X30NL2 0T20 | CMP-1013-00510-2 | 11

3296W-1-103RLF | TRIMMER 10K OHM 0.5W PC PIN TOP | R3 | FP-3296W-MFG | CMP-07234-000024-1 | 1

CRCW08051M00JNEA | | R4 | RESC2013X50X30NL2 0T20 | CMP-2001-03632-1 | 1

3296W-1-105LF | TRIMMER 1M OHM 0.5W PC PIN TOP | R9 | FP-3296W-MFG | CMP-2000-05583-2 | 1

CRCW0805220RFKEA | RES Thick Film, 220Ω, 1%, 0.125W, 100ppm/°C, 0805 | R10, R11, R12, R13, R14, R15, R16, R17, R18, R19, R20, R21, R22, R23, R24, R25, R26, R27, R28, R29, R30, R31, R32, R33, R34 | FP-CRCW0805-e3-MFG | CMP-2001-03682-2 | 25

0805W8F5101T5E | 5.1kΩ ±1% 0.125W ±100ppm/℃ 0805 Chip Resistor - Surface Mount RoHS | R40, R41 | RESC2013X50X30NL2 0T20 | CMP-1013-00510-2 | 2

0805W8F3302T5E | 33K, 0805 Chip Resistor, UniOhm | R42 | RESC2013X50X30NL2 0T20 | CMP-1013-00510-2 | 1

K2-1102SP-C4SC-04 | Swicth, SPST, 24 V, -35 to 85 degC, 4-Pin SMD, RoHS, Tape and Reel | SW1, SW2, SW4, SW5, SW6, SW7, SW8 | TECO-FSM4JSMA_V | CMP-2000-05602-2 | 7

SS-12D02-VG4 | SPDT, Korean Hroparts Elec SS-12D02-VG4 | SW3 | 5_2-54mm_SPDT | SS-12D02-VG4 | 1

WD65C22 I/O Controller | WD65C22 PDIP-40, I/O Controller | U1 | PDIP_40 | WD65C22 | 1

AT28C256 | Paged Parallel EEPROM AT28C256 | U2 | DIP_28 | AT28C256 | 1

62256 | 32K x 8, SRAM | U3 | DIP_28 | 62256 | 1
6502 Processor | WDC 6502 PDIP-40 | U4 | PDIP_40 | WDC65C02 | 1
2X16 LCD Display | 2X16 LCD Display, Parallel input | U5 | LCD_2x16 | LCM1602C | 1

74HC00N | Quad 2-input NAND gate, CMOS, 2 to 6 V, -40 to 125 degC, 14-Pin DIP (SOT27-1), RoHS, Bulk | U6 | NXP-SOT27-1-14 | CMP-0976-00001-1 | 1

LM555CN | Timer, 8-pin MDIP | U7, U8, U9 | N08E | CMP-0056-00017-2 | 3
SN74LS08N | Quadruple 2-Input Positive-AND Gates, N0014A, TUBE | U10 | N0014A | CMP-0777-00259-3 | 1

SN74LS04N | Hex inverters, N0014A, TUBE | U11 | N0014A | CMP-1615-00911-2 | 1

SN74LS32N | Quad 2-input positive-OR gates, N0014A, TUBE | U12 | N0014A | CMP-1573-00145-3 | 1

SN74HC14N | Hex Schmitt-Trigger Inverters, N0014A, TUBE | U13 | N0014A | CMP-1615-00889-3 | 1

SN74HC595N | 8-Bit Shift Registers With 3-State Output Registers, N0016A, TUBE | U14, U15 | N0016A | CMP-0780-00137-3 | 2

OSC-12.9MM-1MHZ | 12.9MM x 12.9MM, 1MHz Can Oscillator | X1 | OSC_THT_12-9MM | OSC-12.9MM-1MHZ | 1

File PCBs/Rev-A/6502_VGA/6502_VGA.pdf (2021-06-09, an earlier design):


to probe address and data bus, be careful


4 | | 1 3
5 | | 1 2 | | 2
6 | | 1 1

4 | 1 3
5 | 1 2 | U 2 D | 5
6 | 1 1


4 | 1 3
5 | 1 2
6 | 1 1

1 0
7 | 1 4

4 | 1 3 | Q 5
1 6 | 8 | | 9 | 8 | Q

1 0 | E N T RCO E N P A Q A B Q B C Q C D Q D VCC G N D | 1 5 | SN 7 4 LS3 0 N
7 | | 1 4


A1 2
A2 3
A3 4
A4 5


Comment | Description | Designator | Footprint | LibRef | Quantity
61304021121 | THT Vertical Pin Header WR-PHD, Pitch 2.54 mm, Dual Row, 40 pins | P1 | 61304021121 | CMP-1502-01135-1 | 1
CRCW0805680RFKEA | | R1, R3, R5 | RESC2013X50X30NL2 0T20 | CMP-2001-04066-1 | 3
RC0805FR-071K5L | RES 1.50K OHM 1/8W 1% 0805 SMD | R2, R4, R6 | RESC2013X60X35LL10 T20 | CMP-1659-00010-2 | 3
SN74LS30N | 8-input positive-NAND gates, N0014A, TUBE | U1, U4, U7, U8, U11, U14, U17, U18 | N0014A | CMP-1627-00459-2 | 8
SN74LS04N | Hex inverters, N0014A, TUBE | U2, U9, U12 | N0014A | CMP-1615-00911-2 | 3
SN74LS161AN | Synchronous 4-Bit Binary Counters, N0016A, TUBE | U3, U6, U10, U13, U16, U19 | N0016A | CMP-1623-00512-2 | 6
SN74LS00N | Quad 2-input positive-NAND gates, N0014A, TUBE | U5, U15, U24 | N0014A | CMP-1627-00476-2 | 3
SN74LS245N | IC TXRX NON-INVERT 5.25V 20DIP | U20, U21, U23 | FP-N0020A-MFG | CMP-1620-00419-3 | 3
SN74HC74N | Dual D-Type Positive-Edge-Triggered Flip-Flops With Clear and Preset, N0014A, TUBE | U22 | N0014A | CMP-1616-00096-3 | 1
VGA D Sub Connector | VGA D Sub Connector | VGA | VGA | VGA-002 | 1
OSC-12.9MM-10MHZ | 12.9MM x 12.9MM, 1MHz Can Oscillator | X1 | OSC_THT_12-9MM | OSC-12.9MM-1MHZ | 1

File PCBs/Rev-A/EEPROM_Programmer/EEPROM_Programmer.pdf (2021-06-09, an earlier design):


ARDUINO NANO EEPROM PROGRAMMER

2 3

1 4 | | 5
1 6 | | 6



Comment | Description | Designator | Footprint | LibRef | Quantity
Arduino Nano | Arduino Nano board | MD1 | ARDUINO_NANO | Arduino_Nano | 1
AT28C256 | Paged Parallel EEPROM AT28C256 | U1 | DIP_28 | AT28C256 | 1

SN74HC595N | 8-Bit Shift Registers With 3-State Output Registers, N0016A, TUBE | U2, U3 | N0016A | CMP-0780-00137-3 | 2

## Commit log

2021-06-09 initial commit for hardware
    [6502.PrjPcb, 6502_VGA.PcbDoc, 6502_VGA.PrjPcb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]
2021-07-01 Rev B
    [6502.PrjPcb, 6502_VGA.PcbDoc, 6502_VGA.PrjPcb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]
